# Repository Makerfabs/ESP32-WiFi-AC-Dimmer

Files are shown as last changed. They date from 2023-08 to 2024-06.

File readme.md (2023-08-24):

# Makerfabs ESP32 WiFi AC Dimmer

```c++
/*
Version:        V1.0
Author:            Vincent
Create Date:    2023/8/7
Note:

*/
```



[TOC]

# Makerfabs

[Makerfabs home page](https://www.makerfabs.com/)

[Makerfabs Wiki](https://wiki.makerfabs.com/)

# Makerfabs ESP32 WiFi AC Dimmer

## Intruduce

Product Link ：[WIFI AC Dimmer Switch](https://www.makerfabs.com/wifi-ac-dimmer-switch.html) 

Wiki Link : []()

Arduino ATmega328P as MCU, inherited Ra-08 Lorawan module and 4 relays.

## Feature

- On-board AC-DC, No external power supply needed;
- On Board Relay to totally shut down current leakage;
- ESP32;
- Suitable for AC 110V~230V, Any frequency;
- Max Load: 2KW;

### Front:

front

### Back:

back

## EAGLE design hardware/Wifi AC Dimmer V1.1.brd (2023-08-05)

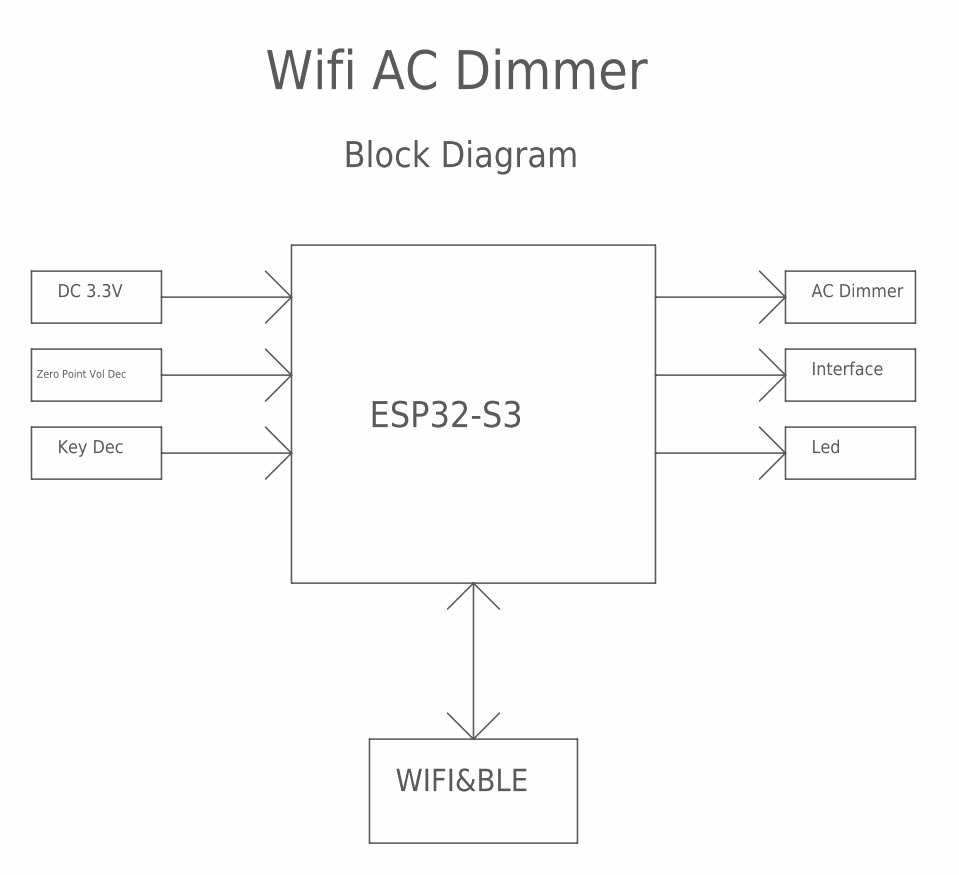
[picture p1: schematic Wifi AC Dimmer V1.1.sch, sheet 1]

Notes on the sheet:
ESP32-S3
DC 3.3V
Zero Point Vol Dec
Key Dec
AC Dimmer
Interface
Led
WIFI&BLE
Block Diagram
Wifi AC Dimmer

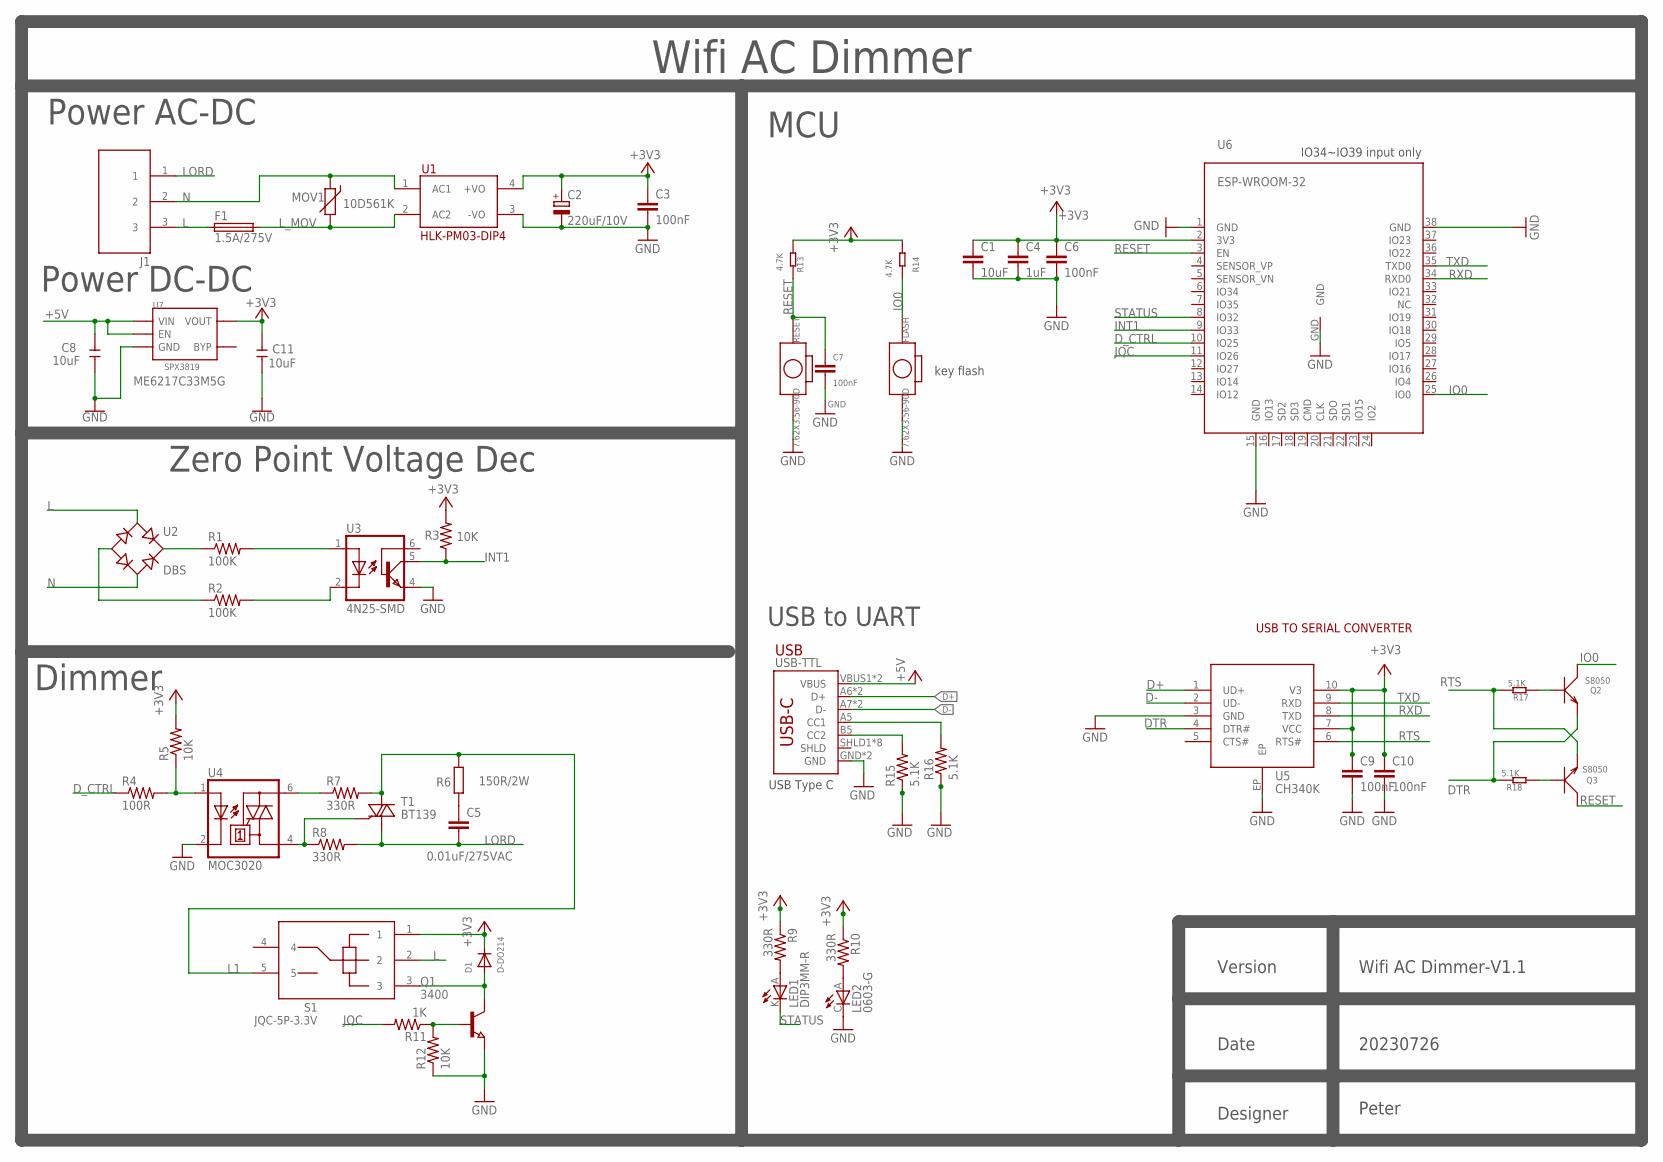
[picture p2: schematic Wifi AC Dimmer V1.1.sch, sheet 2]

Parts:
C1, C8, C11: 10uF; C0603
C2: 220uF/10V; SMD-6.3*5
C3, C6, C7, C9, C10: 100nF; C0603
C4: 1uF; C0603
C5: 0.01uF/275VAC; XC10B6
D1: D-DO214; DO-214
F1: 1.5A/275V; PICOFUSE
FLASH: 7.62X3.56-90D; 2P-7.62X3.56-90D
J1: DBT50G-9.5-3P; THROUGH-HOLE-9.5
LED1: DIP3MM-R; LED-3MM
LED2: 0603-G; LED0603
MOV1: 10D561K; S10K11
Q1: 3400; SOT-23
Q2, Q3: S8050; SOT23
R1, R2: 100K; R0805
R3, R5, R12: 10K; R0603
R4: 100R; R0603
R6: 150R/2W; R-0617
R7, R8: 330R; R0805
R9, R10: 330R; R0603
R11: 1K; R0603
R13, R14: 4.7K; R0603
R15, R16, R17, R18: 5.1K; R0603
RESET: 7.62X3.56-90D; 2P-7.62X3.56-90D
S1: JQC-5P-3.3V; JQC-5P-5V
T1: BT139; TO220CL
U1: HLK-PM03-DIP4; HLK-PM03
U2: DBS; DB-S
U3: 4N25-SMD; DIL6-SMD
U4: MOC3020; DIL6-SMD
U5: CH340K; ESOP-10-EP-150MIL
U6: ESP-WROOM-32
U7: SPX3819; SOT23-5
USB-TTL: USB_C5; USB-C-16P-5

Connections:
+3V3: C1.1, C2.+, C3.1, C4.1, C6.1, C9.1, C10.1, C11.2, D1.C, R3.2, R5.2, R9.1, R10.1, R13.2, R14.2, S1.1, U1.4 (+VO), U5.7 (VCC), U5.10 (V3), U6.2 (3V3), U7.5 (VOUT)
+5V: C8.2, U7.1 (VIN), U7.3 (EN), USB-TTL.VBUS1 (VBUS), USB-TTL.VBUS2 (VBUS)
D+: U5.1 (UD+), USB-TTL.A6 (D+), USB-TTL.B6 (D+)
D-: U5.2 (UD-), USB-TTL.A7 (D-), USB-TTL.B7 (D-)
DTR: Q2.2 (E), R18.1, U5.4 (DTR#)
D_CTRL: R4.1, U6.10 (IO25)
GND: C1.2, C2.-, C3.2, C4.2, C6.2, C7.2, C8.1, C9.2, C10.2, C11.1, FLASH.P$2 (2), LED2.C, Q1.2 (E), R12.1, R15.1, R16.1, RESET.P$2 (2), U1.3 (-VO), U3.4 (EMI), U4.2 (C), U5.3 (GND), U5.EP, U6.1 (GND), U6.15 (GND), U6.38 (GND), U6.GND, U7.2 (GND), USB-TTL.GND, USB-TTL.GND2 (GND)
INT1: R3.1, U3.5 (COL), U6.9 (IO33)
IO0: FLASH.P$1 (1), Q2.3 (C), R14.1, U6.25 (IO0)
JQC: R11.2, U6.11 (IO26)
L: F1.1, J1.3, S1.2, U2.AC1
L1: R6.2, R7.2, S1.5, T1.A (A2)
LORD: C5.2, J1.1, R8.2, T1.C (A1)
L_MOV: F1.2, MOV1.2, U1.2 (AC2)
N: J1.2, MOV1.1, U1.1 (AC1), U2.AC2
unnamed: Q1.1 (B), R11.1, R12.2
unnamed: D1.A, Q1.3 (C), S1.3
unnamed: R1.2, U3.1 (A)
unnamed: R2.1, U2.-
unnamed: R2.2, U3.2 (C)
unnamed: R7.1, U4.6 (A2)
unnamed: R8.1, T1.G, U4.4 (A1)
unnamed: C5.1, R6.1
unnamed: LED1.A, R9.2
unnamed: R4.2, R5.1, U4.1 (A)
unnamed: LED2.A, R10.2
unnamed: Q3.1 (B), R18.2
unnamed: Q2.1 (B), R17.2
unnamed: R1.1, U2.+
unnamed: R16.2, USB-TTL.A5 (CC1)
unnamed: R15.2, USB-TTL.B5 (CC2)
RESET: C7.1, Q3.3 (C), R13.1, RESET.P$1 (1), U6.3 (EN)
RTS: Q3.2 (E), R17.1, U5.6 (RTS#)
RXD: U5.8 (TXD), U6.34 (RXD0)
STATUS: LED1.K (C), U6.8 (IO32)
TXD: U5.9 (RXD), U6.35 (TXD0)

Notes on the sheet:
Wifi AC Dimmer
Power AC-DC
Zero Point Voltage Dec
Dimmer
MCU
Version
Date
Designer
Wifi AC Dimmer-V1.1
20230726
Peter
IO34~IO39 input only
key flash
USB to UART
USB TO SERIAL CONVERTER
USB
USB Type C
ME6217C33M5G
Power DC-DC

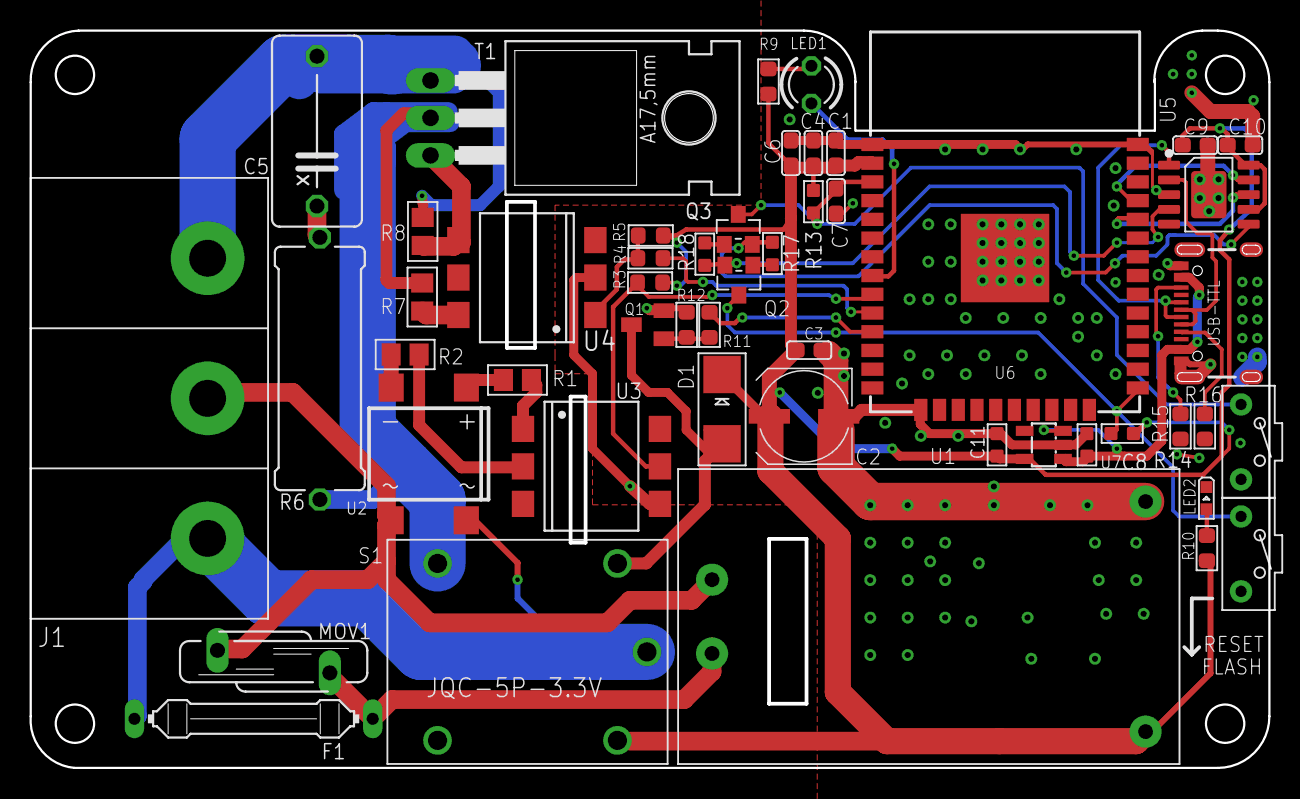
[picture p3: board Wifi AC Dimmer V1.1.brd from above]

Board: 2 copper layers, 84.0 x 50.0 mm, 51 parts (1 on the bottom side), 36 nets.

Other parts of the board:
U$6: MAKERFABS_0.3

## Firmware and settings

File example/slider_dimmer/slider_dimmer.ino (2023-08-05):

#include <arduino.h>
#include <WiFi.h>
#include <WiFiClient.h>

// s3
// #define SCR_Pin 9
// #define RELAY_PIN 20
// #define LED_PIN 19
// #define ZCD_PIN 10

// ESP32
#define SCR_Pin 25
#define RELAY_PIN 26
#define LED_PIN 32
#define ZCD_PIN 33

#define AC_CTRL_OFF digitalWrite(SCR_Pin, LOW)
#define AC_CTRL_ON digitalWrite(SCR_Pin, HIGH)

#define RELAY_OFF digitalWrite(RELAY_PIN, LOW)
#define RELAY_ON digitalWrite(RELAY_PIN, HIGH)

#define LED_OFF digitalWrite(LED_PIN, HIGH)
#define LED_ON digitalWrite(LED_PIN, LOW)

unsigned char dim = 0;

WiFiServer server(80);

const char mainPage[] PROGMEM = R"rawliteral(
<!DOCTYPE HTML><html>
<head>
  <meta name="viewport" content="width=device-width, initial-scale=1">
  <title>ESP WiFi Dimmer</title>
  <style>
    html {font-family: Arial; display: inline-block; text-align: center;}
    h2 {font-size: 2.3rem;}
    p {font-size: 1.9rem;}
    body {max-width: 400px; margin:0px auto; padding-bottom: 25px;}
    .slider { -webkit-appearance: none; margin: 14px; width: 360px; height: 25px; background: #FFD65C;
      outline: none; -webkit-transition: .2s; transition: opacity .2s;}
    .slider::-webkit-slider-thumb {-webkit-appearance: none; appearance: none; width: 35px; height: 35px; background: #003249; cursor: pointer;}
    .slider::-moz-range-thumb { width: 35px; height: 35px; background: #003249; cursor: pointer; } 
  </style>
</head>
<body>
  <h2>ESP Web Server</h2>
  <p><span id="textSliderValue">%SLIDERVALUE%</span></p>
  <p><input type="range" onchange="updateSliderPWM(this)" id="pwmSlider" min="0" max="100" value="%SLIDERVALUE%" step="1" class="slider"></p>
<script>
function updateSliderPWM(element) {
  var sliderValue = document.getElementById("pwmSlider").value;
  document.getElementById("textSliderValue").innerHTML = sliderValue;
  console.log(sliderValue);
  var xhr = new XMLHttpRequest();
  xhr.open("GET", "/update?value="+sliderValue, true);
  xhr.send();
}
</script>
</body>
</html>
)rawliteral";

void setup()
{
    pinMode(LED_PIN, OUTPUT);
    pinMode(RELAY_PIN, OUTPUT);
    pinMode(SCR_Pin, OUTPUT);
    pinMode(ZCD_PIN, INPUT);
    LED_OFF;
    RELAY_OFF;
    AC_CTRL_OFF;

    Serial.begin(115200); // initialize the serial communication:
    delay(1000);

    RELAY_ON;
    AC_CTRL_ON;
    delay(2000);
    RELAY_OFF;
    AC_CTRL_OFF;

    server_setup();

    attachInterrupt(ZCD_PIN, zero_cross_int, RISING); // CHANGE FALLING RISING

    Serial.println("Test begin");
    set_power(5);
}

void loop()
{
    dimmer_server();

    // for (i = 1; i < 10; i++)
    // {
    //     set_power(i);
    //     delay(500);
    // }
    // set_power(0);
    // delay(1000);
}

void zero_cross_int() // function to be fired at the zero crossing to dim the light
{
    if (dim < 5)
        return;
    if (dim > 90)
        return;

    int dimtime = (100 * dim);
    delayMicroseconds(dimtime); // Off cycle
    AC_CTRL_ON;                 // triac firing
    delayMicroseconds(500);     // triac On propagation delay
    AC_CTRL_OFF;                // triac Off
}

void set_power(int level)
{
    dim = map(level, 0, 100, 95, 5);
    if (level == 0)
    {
        RELAY_OFF;
    }
    else
        RELAY_ON;
}

void server_setup()
{
    WiFi.disconnect();

    WiFi.begin("Makerfabs", "20160704");

    int connect_count = 0;
    while (WiFi.status() != WL_CONNECTED)
    {
        vTaskDelay(500);
        Serial.print(".");
        connect_count++;
        if (connect_count > 20)
        {
            Serial.println("Wifi error");
            break;
        }
    }

    if (WiFi.status() == WL_CONNECTED)
    {
        Serial.println("");
        Serial.println("WiFi connected");
        Serial.println("IP address: ");
        Serial.println(WiFi.localIP());
    }

    server.begin();
}

void dimmer_server()
{

    WiFiClient client = server.available(); // listen for incoming clients

    if (client) // if you get a client,
    {
        Serial.println("---------------------------------------------------");
        Serial.println("New Client.");
        String currentLine = "";
        while (client.connected())
        { // loop while the client's connected
            if (client.available())
            {
                char c = client.read();
                Serial.write(c);

                // PAGE:192.168.4.1
                if (c == '\n')
                { // if the byte is a newline character

                    if (currentLine.length() == 0)
                    {
                        client.println("HTTP/1.1 200 OK");
                        client.println("Content-type:text/html");
                        client.println();

                        client.println(mainPage);
                        client.stop();

                        return;
                    }
                    else
                    {
                        currentLine = "";
                    }
                }
                else if (c != '\r')
                {
                    currentLine += c;
                }

                // API:保存设置
                if (currentLine.endsWith("GET /update"))
                {
                    String get_request = "";
                    // read GET next line
                    while (1)
                    {
                        char c_get = client.read();
                        Serial.write(c_get);
                        if (c_get == '\n')
                        {
                            break;
                        }
                        else
                        {
                            get_request += c_get;
                        }
                    }

                    client.println("HTTP/1.1 200 OK");
                    client.println("Content-type:text/html");
                    client.println();
                    // client.println(mainPage);
                    client.println("Update Over");
                    client.println();
                    client.stop();

                    Serial.println(get_request);
                    req_explain(get_request);

                    return;
                }
            }
        }
        // close the connection:
        client.stop();
        Serial.println("Client Disconnected.");
    }
    return;
}

void req_explain(String str)
{
    char temp[50];

    str.replace("&", " ");
    sprintf(temp, "%s", str.c_str());
    Serial.println(temp);

    int var_1 = 0;

    sscanf(temp, "?value=%d HTTP", &var_1);
    Serial.println(var_1);

    set_power(var_1);
}

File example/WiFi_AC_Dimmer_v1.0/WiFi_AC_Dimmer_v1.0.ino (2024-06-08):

#include <arduino.h>

////////////////////////////////////////////////////////////////////////////////////////////////////////////////////////

// IO Configuration

////////////////////////////////////////////////////////////////////////////////////////////////////////////////////////
// ESP32
#define SCR_Pin 25
#define RELAY_PIN 26
#define LED_PIN 32
#define ZCD_PIN 33

#define AC_CTRL_OFF digitalWrite(SCR_Pin, LOW)
#define AC_CTRL_ON digitalWrite(SCR_Pin, HIGH)

#define RELAY_OFF digitalWrite(RELAY_PIN, LOW)
#define RELAY_ON digitalWrite(RELAY_PIN, HIGH)

#define LED_OFF digitalWrite(LED_PIN, HIGH)
#define LED_ON digitalWrite(LED_PIN, LOW)
////////////////////////////////////////////////////////////////////////////////////////////////////////////////////////

// Parameter Initialization

////////////////////////////////////////////////////////////////////////////////////////////////////////////////////////
unsigned char dim = 0; // Initial brightness level from 0 to 100, change as you like!
unsigned char i;
unsigned long int zcd_num = 0;
int delay_flag = 0;
long command_time = 0;

void setup()
{
  pinMode(LED_PIN, OUTPUT);   // initialize the ledPin as an output:
  pinMode(RELAY_PIN, OUTPUT); // initialize the RELAYPin as an output:
  pinMode(SCR_Pin, OUTPUT);   // initialize the RELAYPin as an output:
  LED_OFF;
  RELAY_OFF;
  AC_CTRL_OFF;

  Serial.begin(115200); // initialize the serial communication:
  delay(1000);

  RELAY_ON;
  AC_CTRL_ON;
  delay(3000);

  pinMode(ZCD_PIN, INPUT);                     // initialize the ZCDPin as an input:
  attachInterrupt(ZCD_PIN, zero_cross_int, RISING); // CHANGE FALLING RISING

  Serial.println("test begin v1.2");
}
////////////////////////////////////////////////////////////////////////////////////////////////////////////////////////

// Main Program

////////////////////////////////////////////////////////////////////////////////////////////////////////////////////////
void loop()
{

  for (i = 1; i < 10; i++)
  {
    set_power(i);
    delay(500);
  }
  set_power(0);
  delay(1000);
}
////////////////////////////////////////////////////////////////////////////////////////////////////////////////////////

// Zero_Cross

////////////////////////////////////////////////////////////////////////////////////////////////////////////////////////
void zero_cross_int() // function to be fired at the zero crossing to dim the light
{
  if (dim < 5)
    return;
  if (dim > 90)
    return;

  int dimtime = (100 * dim);  // For 60Hz =>65
  delayMicroseconds(dimtime); // Off cycle
  AC_CTRL_ON;                 // triac firing
  delayMicroseconds(500);     // triac On propagation delay (for 60Hz use 8.33)
  AC_CTRL_OFF;                // triac Off
}

// 0 ~ 10
void set_power(int level)
{
  if (level == 0)
  {
    dim = 95;
    RELAY_OFF;
  }
  if (level == 10)
  {
    dim = 5;
    RELAY_ON;
  }
  if (level < 10 && level > 0)
  {
    dim = 10 * (9 - level);
    RELAY_ON;
  }
}

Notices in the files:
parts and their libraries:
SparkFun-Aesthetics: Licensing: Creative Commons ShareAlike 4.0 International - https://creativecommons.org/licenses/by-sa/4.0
